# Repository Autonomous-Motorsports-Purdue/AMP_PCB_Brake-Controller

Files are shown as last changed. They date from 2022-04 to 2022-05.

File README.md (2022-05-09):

# AMP_PCB_Brake-Controller
PCB with brake motor controller files and documentation

## Features
- Breakout board form factor for easy replacement
- Large maximum current rating (50A continuous, 117A pulse)
- Motor driver (currently) still in production

## Testing
- [X] Order PCB
- [X] Assemble PCB
- [ ] Test PCB independently
  - [X] Simple forward/reverse polarity
  - [X] Higher current (motor) load
  - [ ] PWM forward/reverse
  - [X] PWM motor load
- [ ] Test PCB on kart

## Notes
- Find reverse polarity protection MOSFET and suitable zener diode
  - MOSFET package: TO-252
  - Zener package: SOT-23
- Use largest 0805 capacitor for C7 (1000uF in schematic)
- To add reverse polarity protection, solder Q1, D1, R1
- To bypass reverse polarity protection, bridge JP1
- All passive components are 0805 package size

---

## Useful figures

Operation truth table:

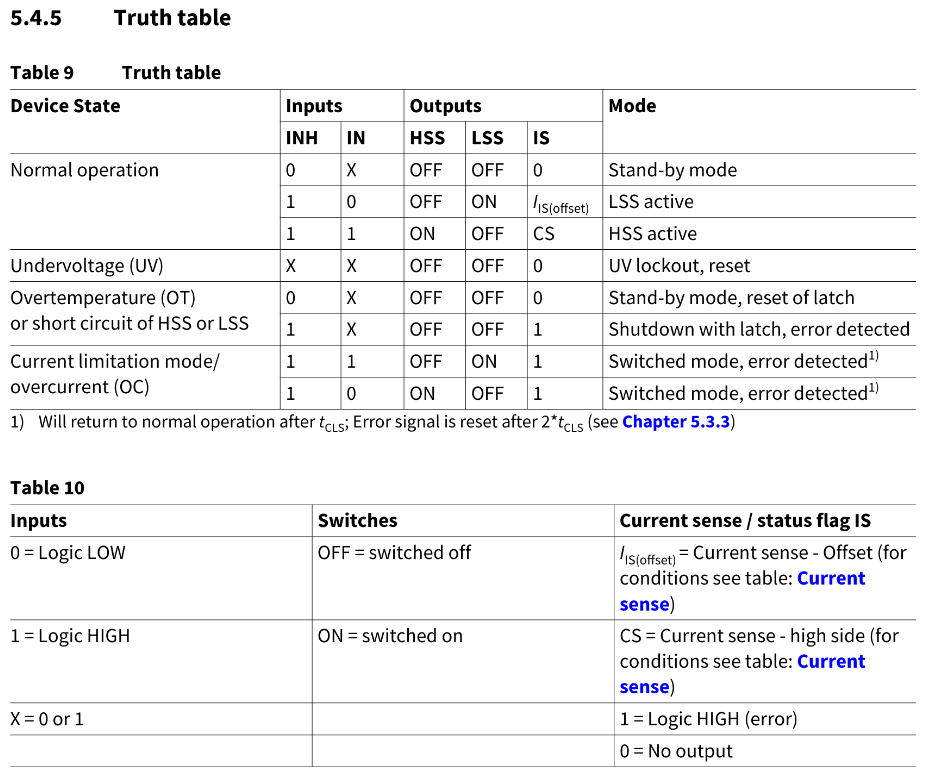
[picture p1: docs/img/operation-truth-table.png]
Operation truth table


Absolute maximum ratings:

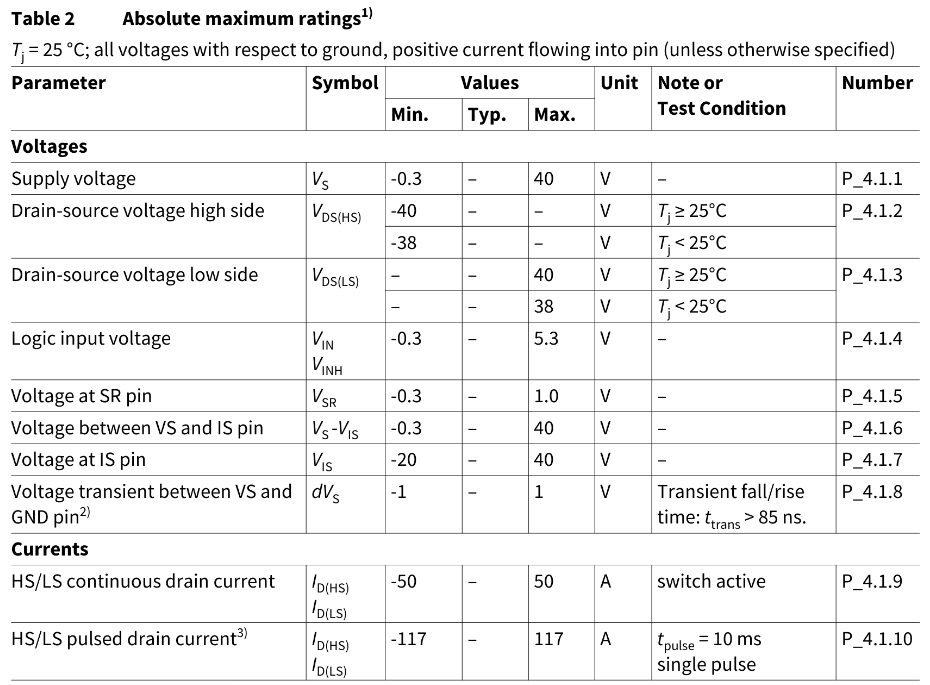
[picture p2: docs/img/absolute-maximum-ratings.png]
Absolute maximum ratings


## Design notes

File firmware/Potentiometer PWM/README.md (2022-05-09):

This code uses an Arduino-compatible board and a potentiometer to create an adjustable PWM output

Please use a function generator instead

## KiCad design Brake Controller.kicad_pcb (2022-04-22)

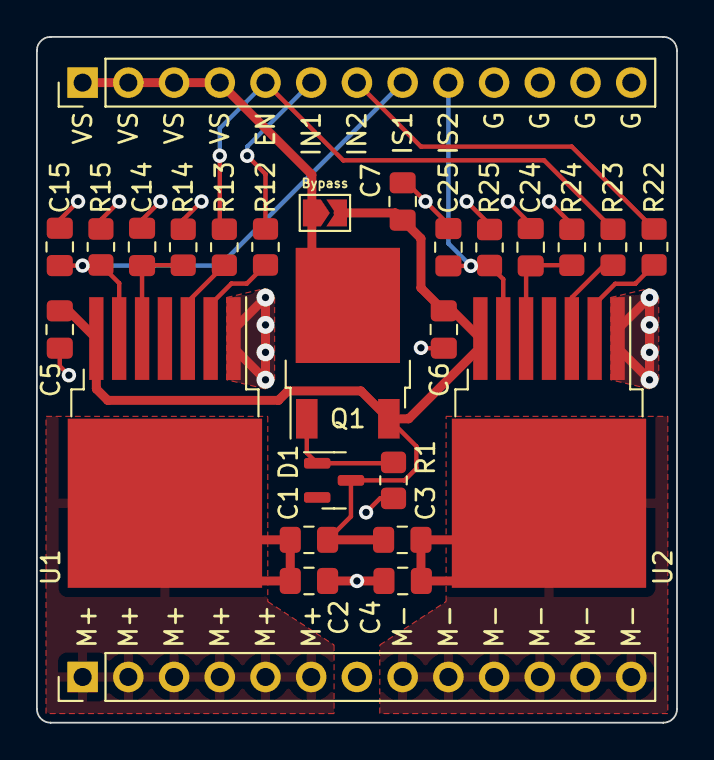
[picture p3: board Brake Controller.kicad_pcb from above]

Board: 2 copper layers, 35.6 x 38.1 mm, 27 parts (0 on the bottom side), 17 nets.

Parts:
C1, C2, C3, C4: 220nF; C_0805_2012Metric_Pad1.18x1.45mm_HandSolder
C5, C6: 100nF; C_0805_2012Metric_Pad1.18x1.45mm_HandSolder
C7: 1000uF; C_0805_2012Metric_Pad1.18x1.45mm_HandSolder
C14, C24: 1nF; C_0805_2012Metric_Pad1.18x1.45mm_HandSolder
C15, C25: 10nF; C_0805_2012Metric_Pad1.18x1.45mm_HandSolder
D1: 10V; SOT-23
J1: INPUT; PinHeader_1x13_P2.54mm_Vertical
J2: OUTPUT; PinHeader_1x13_P2.54mm_Vertical
JP1: Protection bypass; SolderJumper-2_P1.3mm_Open_TrianglePad1.0x1.5mm
Q1: Q_PMOS_GDS; TO-252-2
R1, R12, R13, R22, R23: 10K; R_0805_2012Metric_Pad1.20x1.40mm_HandSolder
R14, R24: 500; R_0805_2012Metric_Pad1.20x1.40mm_HandSolder
R15, R25: 1K; R_0805_2012Metric_Pad1.20x1.40mm_HandSolder
U1, U2: IFX007T; TO-263-7_TabPin4

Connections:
/EN: J1.5, R13.2, R23.2
/IN1: J1.6, R12.2
/IN2: J1.7, R22.2
/IS1: C15.1, J1.8, R15.1, U1.6 (IS)
/IS2: C25.1, J1.9, R25.1, U2.6 (IS)
/MOTOR+: C1.2, C2.1, J2.1, J2.2, J2.3, J2.4, J2.5, J2.6, U1.4 (OUT)
/MOTOR-: C3.2, C4.1, J2.8, J2.9, J2.10, J2.11, J2.12, J2.13, U2.4 (OUT)
GND: C2.2, C4.2, C5.2, C6.2, C7.2, C14.2, C15.2, C24.2, C25.2, J1.10, J1.11, J1.12, J1.13, R1.2, R14.2, R15.2, R24.2, R25.2, U1.1 (GND), U2.1 (GND)
unnamed: C1.1, C3.1, C5.1, C6.1, C7.1, D1.3 (K), JP1.2 (B), Q1.3 (S), U1.7 (VS), U2.7 (VS)
unnamed: C14.1, R14.1, U1.5 (SR)
unnamed: C24.1, R24.1, U2.5 (SR)
unnamed: D1.1 (A), Q1.1 (G), R1.1
unnamed: R12.1, U1.2 (IN)
unnamed: R13.1, U1.3 (INH)
unnamed: R22.1, U2.2 (IN)
unnamed: R23.1, U2.3 (INH)
VS: J1.1, J1.2, J1.3, J1.4, JP1.1 (A), Q1.2 (D)

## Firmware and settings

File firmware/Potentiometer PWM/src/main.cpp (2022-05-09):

#include <Arduino.h>

#define POT_INPUT A2
#define POT_LOW 0
#define POT_HIGH 1023

#define PWM_OUTPUT 10

void setup() {

  Serial.begin(9600);

  // setup PWM output pin
  pinMode(PWM_OUTPUT, OUTPUT);
}

void loop() {
  
  // read potentiometer value
  int pot_value = map(analogRead(POT_INPUT), POT_LOW, POT_HIGH, 0, 255);
  Serial.println(pot_value);

  // output mapped potentiomer value (PWM)
  analogWrite(PWM_OUTPUT, pot_value);
}

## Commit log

2022-04-04 Initial schematic commit
    [Brake Controller.kicad_pcb, Brake Controller.kicad_sch]
2022-04-04 Add pin headers, prepare for PCB layout
    [Brake Controller.kicad_sch]
2022-04-04 Edit author/schematic title
    [Brake Controller.kicad_sch]
2022-04-04 Fix missing GND labels
    [Brake Controller.kicad_sch]
2022-04-09 Add reverse polarity bypass
    [Brake Controller.kicad_sch]
2022-04-09 Fix motor driver pinout
2022-04-09 Route PCB
    [Brake Controller.kicad_pcb]
2022-04-12 Add larger ground pour to motor driver pin 1
    [Brake Controller-B_Cu.gbr, Brake Controller-B_Mask.gbr, Brake Controller-B_Silkscreen.gbr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]
2022-04-22 Add thermal relief to motor controller connections
    [Brake Controller.kicad_pcb]
2022-05-09 Add adjustable PWM firmware
